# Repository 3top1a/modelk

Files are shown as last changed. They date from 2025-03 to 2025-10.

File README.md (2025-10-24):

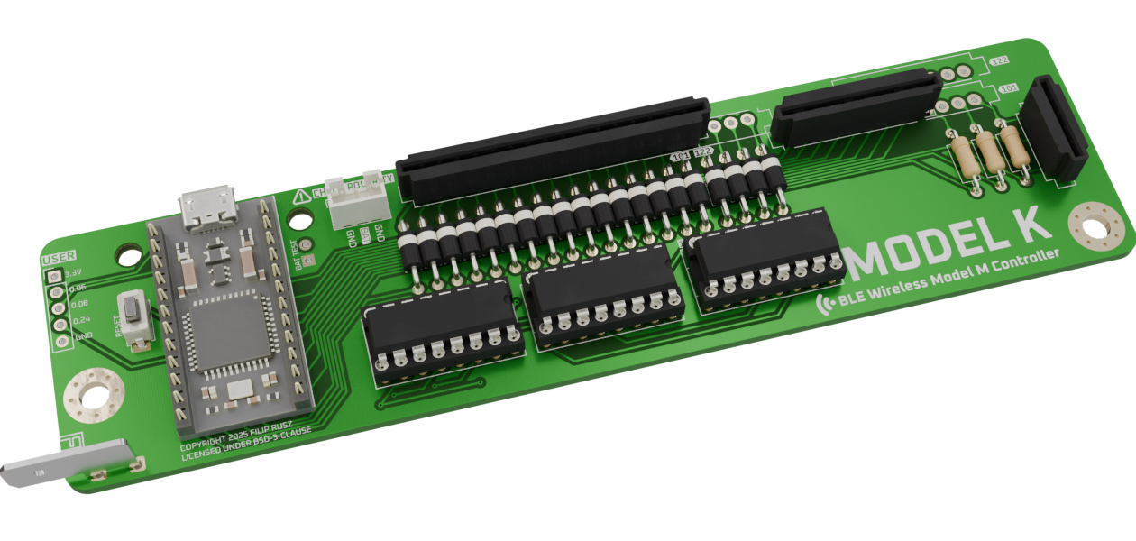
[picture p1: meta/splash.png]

<sup><sub>Render may be of an outdated version, the images below are from a CI/CD render and are always up-to-date. Only compatible with nice!nano, other MCUs won't work</sub></sup>
<div style="display: inline-flex; flex-direction: row; align-content: space-around; justify-content: space-evenly;">
  
  
</div>

Modelk is a custom replacement controller designed to add wireless Bluetooth Low Energy functionality to classic IBM Model M keyboards. This drop-in controller lets you convert your vintage buckling spring keyboard to wireless without permanent modification, preserving the original controller.

## Features

<!-- TODO Supported keyboards, M122 not tested yet -->
- Fully wireless with BLE (Bluetooth Low Energy)
- Battery powered with 3+ weeks of battery life[^batery]
- USB C for drag-and-drop programming, charging and wired use
- Compatible with IBM Model M 101/102 layouts (122-key compatibility uncertain as I do not own one yet)[^models]
- [Open source ZMK firmware](https://github.com/3top1a/modelk-zmk), with [CI/CD builds](https://github.com/3top1a/modelk-zmk/actions/workflows/build.yml)
- Works as a shield for the [nice!nano](https://nicekeyboards.com/nice-nano), built on top of the Nordic nRF52840
- All components are THT and easy to solder/repair/replace
- Three high-frequency user-configurable pins for your solenoid/speaker desires

## Hardware

### PCB

The PCB is designed in KiCad 9. This repository has a CI/CD pipeline that automatically renders the schematic into a [PDF](https://github.com/3top1a/modelk/blob/pcb-artifacts/pcb/autogen/modelk-schematic.pdf)/[SVG](https://github.com/3top1a/modelk/blob/pcb-artifacts/pcb/autogen/modelk-schematic.svg) and generates gerbers for [JLCPCB](https://github.com/3top1a/modelk/blob/pcb-artifacts/pcb/autogen/jlcpcb.zip) and [PCBWAY](https://github.com/3top1a/modelk/blob/pcb-artifacts/pcb/autogen/pcbway.zip).



### Components

See the automatically generated [iBOM](https://github.com/3top1a/modelk/blob/pcb-artifacts/pcb/autogen/ibom.html) (you will need to download the .html file and open it in your browser for now).

For a full assembly, you will need:
- 1x Modelk PCB
- 2x 74HC595 shift register ICs, preferably with DIP-16 sockets (three for M122s)
- 3x 150R resistors for the LEDs (if you have any)
- 16x 1N4148 diodes (20 for M122s)
- 1x 6x3mm reset switch ([GME](https://www.gmelectronic.com/v/1500827/kls-ts3601-43-180-microswitch) for reference)
- 1x battery and its corresponding connector (on board is JST-PH 2mm and a 2.54mm pin header for power profiling)
- PCB Faston mount ([GME](https://www.gmelectronic.com/v/1500147/dj6116-63x08-faston-do-dps-63mm) for reference)
- Appropriate [Trio-mate](https://www.te.com/en/product-6-520415-6.html) or [Connfly](https://www.tme.eu/cz/details/ds1020-16st1d/konektory-ffc-fpc-raster-2-54mm/connfly/) connectors
- 1x nice!nano with Mill Max low profile sockets

Your keyboard might contain 16+12 or 16+8+4 connectors, make sure you order the ones you need! The board supports both of them.

### Equipment

You will need:

- A Temperature-controlled soldering iron
- Some Electronics-grade solder
- Fume extraction or well-ventilated area
- A multimeter for troubleshooting
- Isopropyl alcohol for cleaning
- Kapton tape for securing the battery

### Assembly

Start with a blank PCB and solder the 16 pin connector.

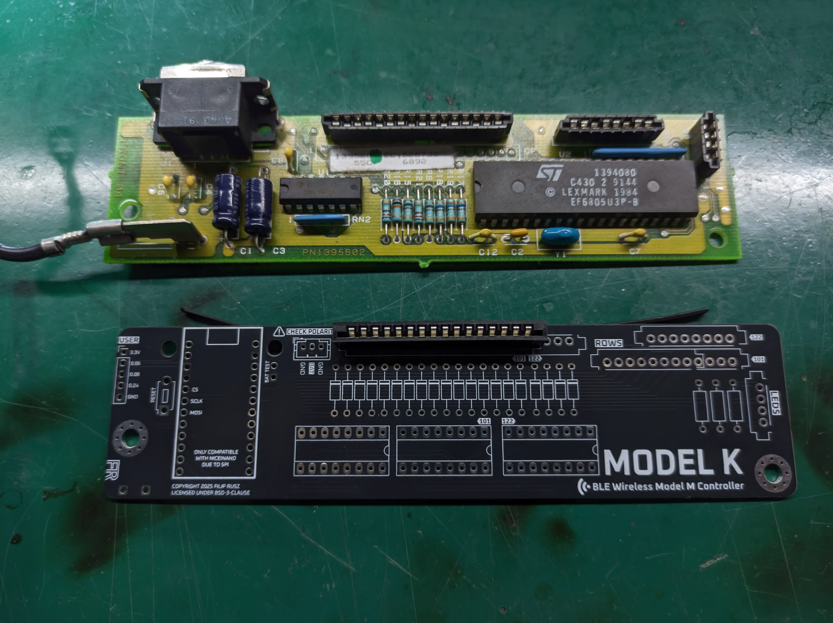
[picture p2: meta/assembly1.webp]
First picture of assembly, Modelk PCB on the bottom with one connector soldered and the original controller on top


On the bottom you can see the board I am assembling (revision [0.10](https://github.com/3top1a/modelk/tree/0.10)), and on the top you can see the original controller that came with my keyboard. Because I am using Connfly connectors and not the original TE Trio-mate, I need to rotate them 180° as they work differently.

> [!IMPORTANT]
> If you are using **Connfly** connectors, make sure to rotate them 180°! This sounds counter-intuitive, but **your board will not work otherwise**!

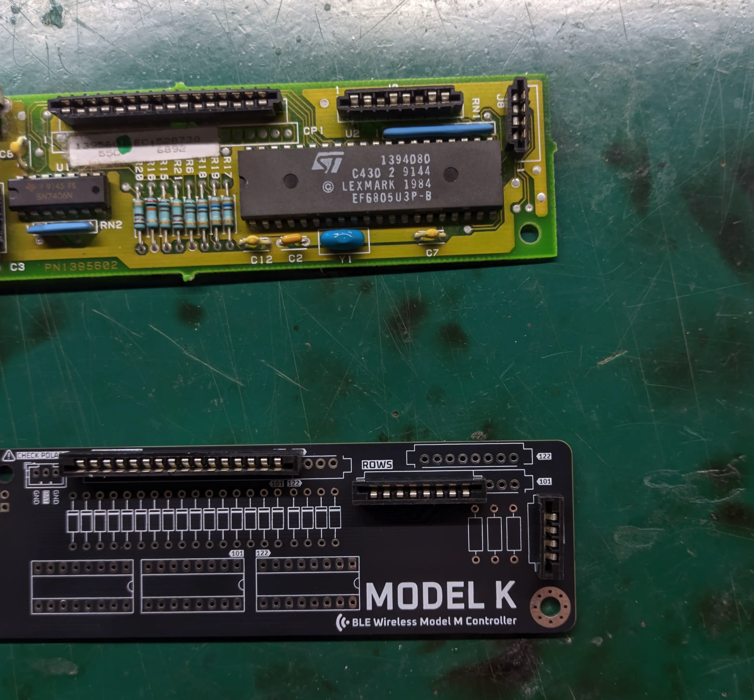
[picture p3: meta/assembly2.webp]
Second picture of assembly, Modelk PCB on the bottom with all connectors soldered and the original controller on top


As my keyboard comes with 16+8+4 connectors, I will solder the appropriate connectors, also rotated just like the 16 pin one.

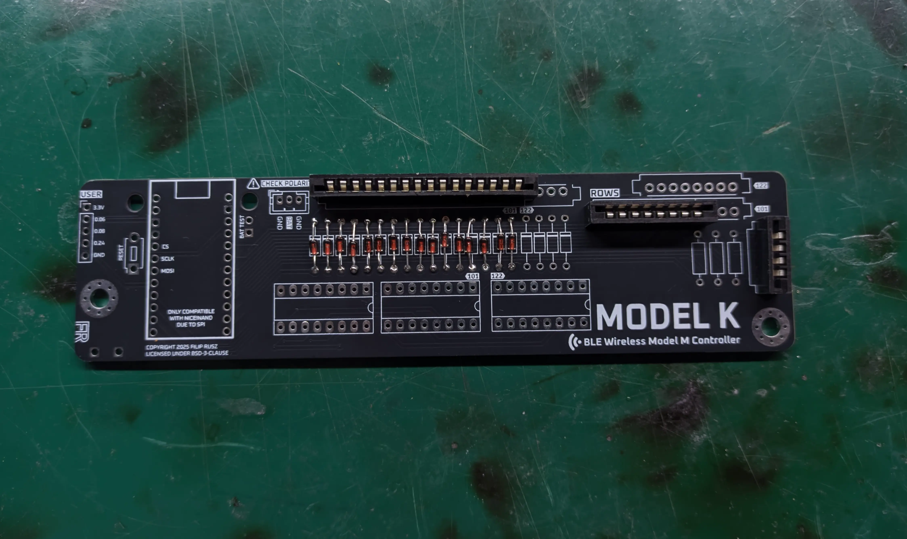
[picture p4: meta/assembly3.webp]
Third picture of assembly, with diodes soldered


Next up are the diodes, as I have a 101-key keyboard, I will only populate the 16 left-most diodes. Pay attention to the orientation of the diodes, the black strip has to be on top, as indicated on the silkscreen.

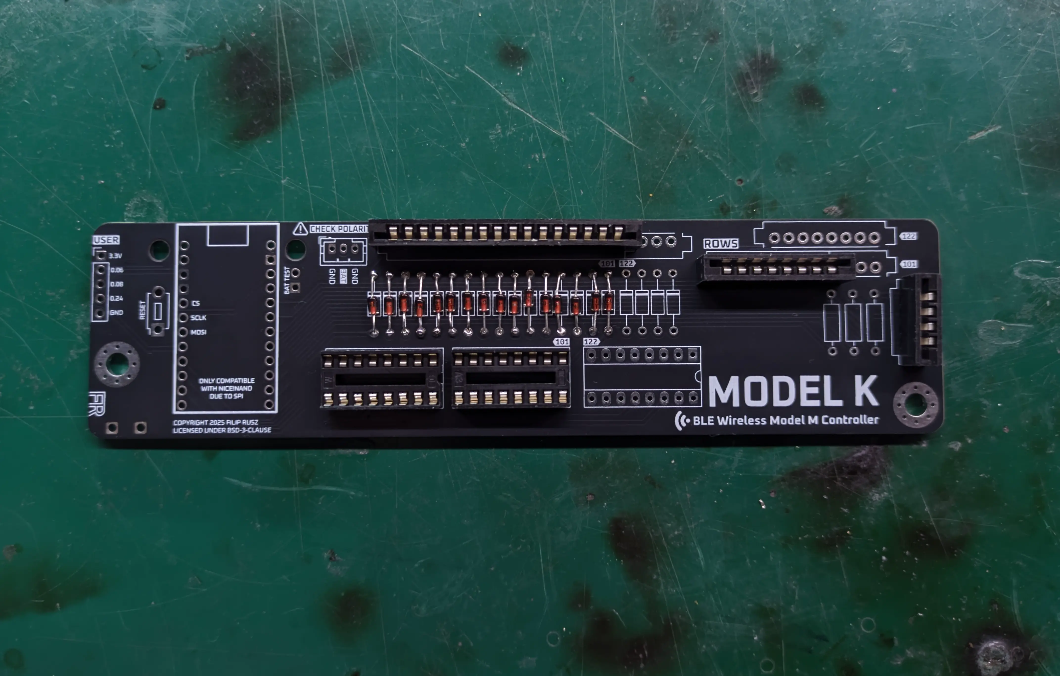
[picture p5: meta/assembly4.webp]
Fourth picture of assembly, with IC sockets soldered


Then the IC sockets, orientation again indicated on the silkscreen (don't forget to populate them!)

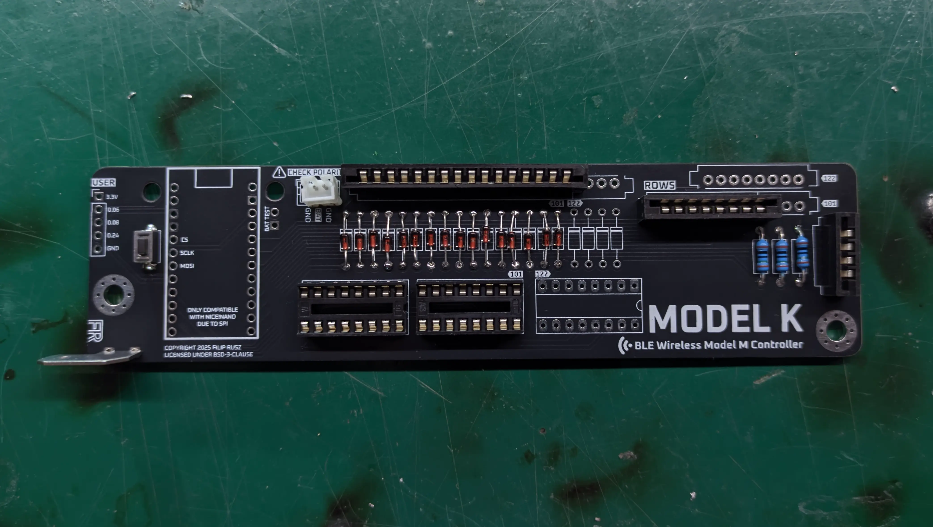
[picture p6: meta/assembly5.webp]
Fifth picture of assembly, with resistors, the reset switch, grounding Faston mount and battery connector soldered


I will skip a bit here, and solder (from left to right) the Faston grounding mount, reset switch, battery connector and resistors. Just be careful soldering the Faston mount, it will get hot.

> [!CAUTION]
> Quadruple check the orientation of the battery connector! The nice!nano doesn't have reverse polarity protection and you will destroy it otherwise.

All that is left is to solder the low profile sockets, solder pins to the nice!nano (see  [official guide](https://nicekeyboards.com/docs/nice-nano/getting-started#socketing-the-nicenano)), and populate the ICs.

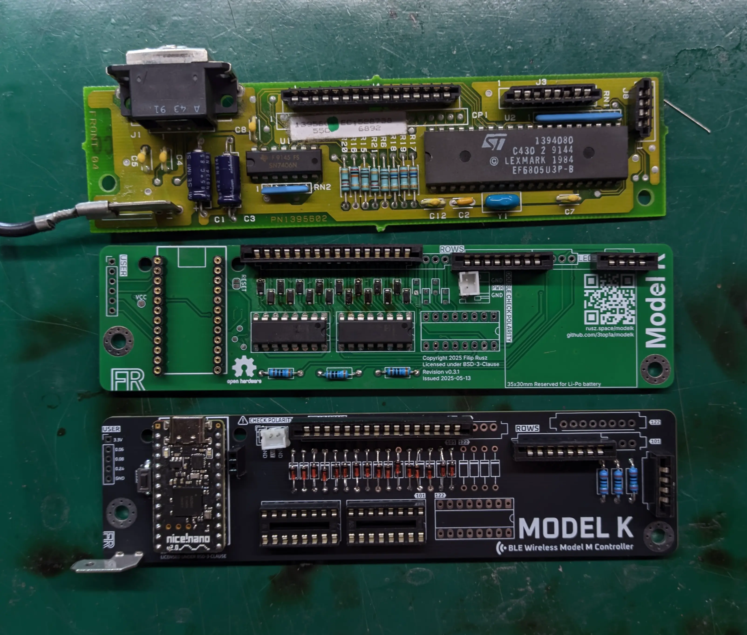
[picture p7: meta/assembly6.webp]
Final picture with finished board on the bottom, a previous iteration in the middle and original controller on top


Here you can see the finished board (without ICs, I forgot and spent 10 minutes debugging SPI because of it), a previous iteration (revision 0.3.1) and the original controller.

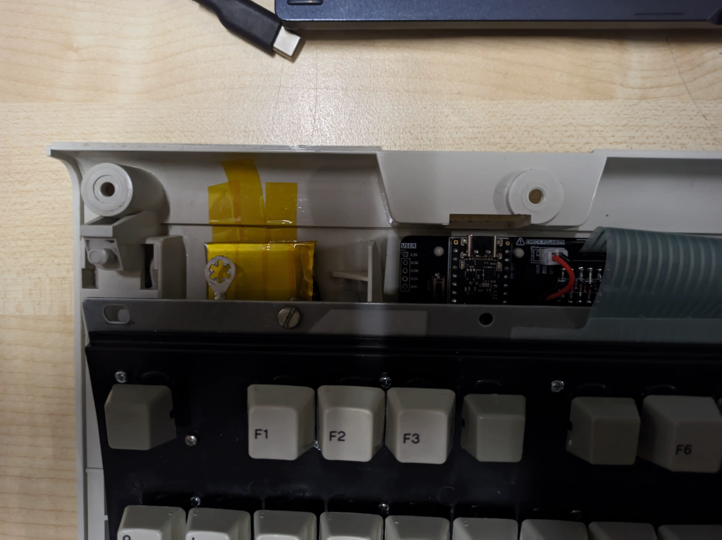
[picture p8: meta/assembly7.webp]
Modelk controller inside a Model M keyboard


Now you just need to put it into the keyboard, secure the battery with kapton tape, and mount the original grounding wire.

## Software

For now, see the [modelk-zmk](https://github.com/3top1a/modelk-zmk) repository for the ZMK firmware. Might get merged into this repository.

Installation:

- Download firmware from the modelk-zmk [CI/CD builds](https://github.com/3top1a/modelk-zmk/actions/workflows/build.yml) ([or click here for the latest firmware](https://nightly.link/3top1a/modelk-zmk/workflows/build/master/firmware.zip))
- Connect your nice!nano via USB
- Double-tap the reset button to enter bootloader mode (the little blue light should stay on)
- Your computer will detect a USB drive
- Drag and drop the firmware file (.uf2) onto this drive
- The nice!nano will disconect itself once the process is complete
- Enjoy a working wireless Model M!

By default, right alt switches to a function layer, where escape toggles USB/BT and F1-F3 toggles BT profiles, F4 clears the current BT profile, F6-F8 controls multimedia, Print Screen unlocks ZMK Studio and **Pause reboots into bootloader for updating firmware**.
You can, of course, completely redesign the layout.

## Credits

Huge kudos go to [John Hawthorn](https://www.johnhawthorn.com/) for his [Model H](https://modelh.club/) controller that inspired this project. This repo started as a fork, but now doesn't share any files.

[^batery]: currently ~3 weeks on a 400mAh battery with revision 0.3.1, will be better on newer boards

[^models]: Tested on: 1386716

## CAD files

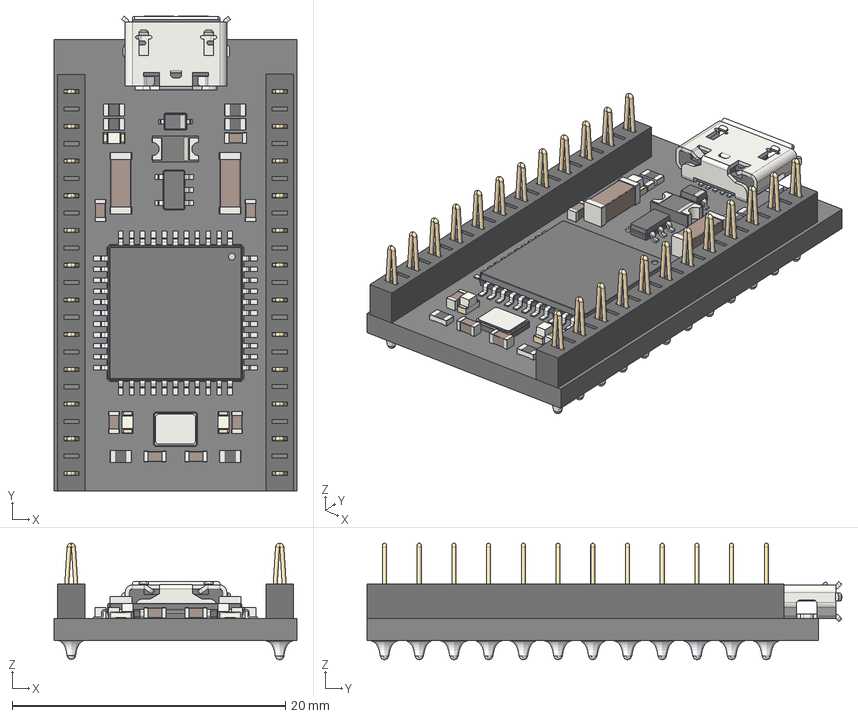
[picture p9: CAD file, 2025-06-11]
pcb/3d/ProMicro.step
17.8 x 34.7 x 8.54 mm
TQFP-44_10x10mm_P0.8mm
USB_Micro-B_Molex_47346-0001
R_0603 x 6
LED_0603_1608Metric x 3
C_0603_1608Metric x 8
Crystal_SMD_3225-4Pin_3.2x2.5mm
D_SOD-323
D_1206_3216Metric
TSOT-23-5
C_1806_4516Metric x 2
conthrough x 2

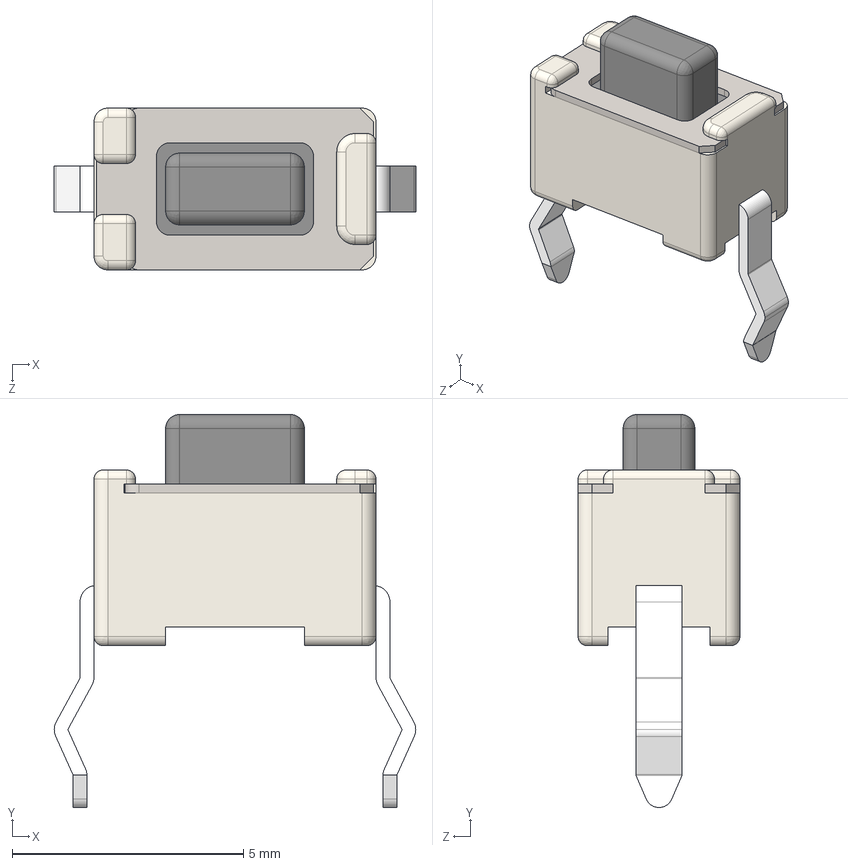
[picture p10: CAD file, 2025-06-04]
pcb/3d/SKHLABA010.stp
7.82 x 8.50 x 3.50 mm

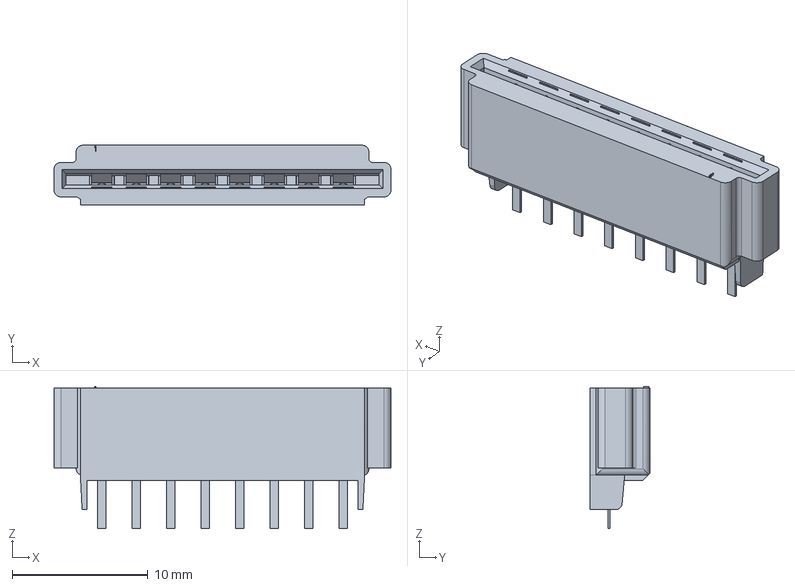
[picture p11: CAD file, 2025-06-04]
pcb/3d/5-520315-8.stp
24.8 x 4.39 x 10.5 mm

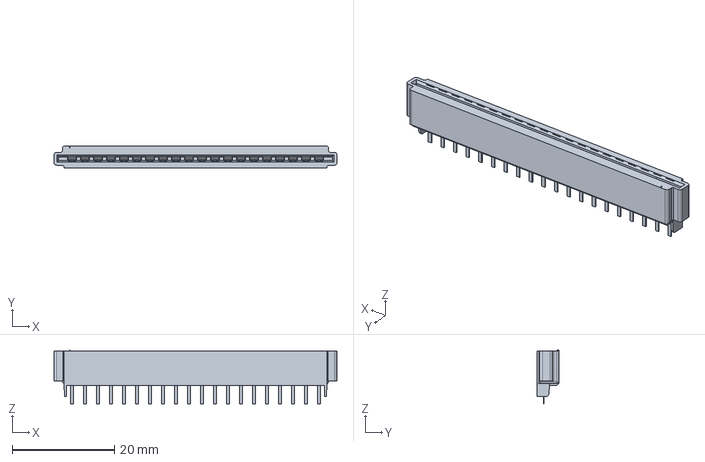
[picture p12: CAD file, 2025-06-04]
pcb/3d/7-520315-0.stp
55.3 x 4.39 x 10.5 mm

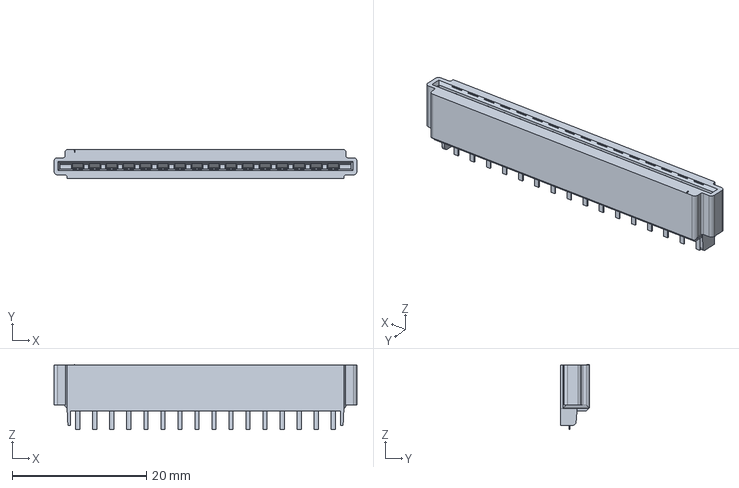
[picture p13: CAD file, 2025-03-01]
pcb/3d/6-520415-6.stp
45.2 x 4.39 x 9.73 mm

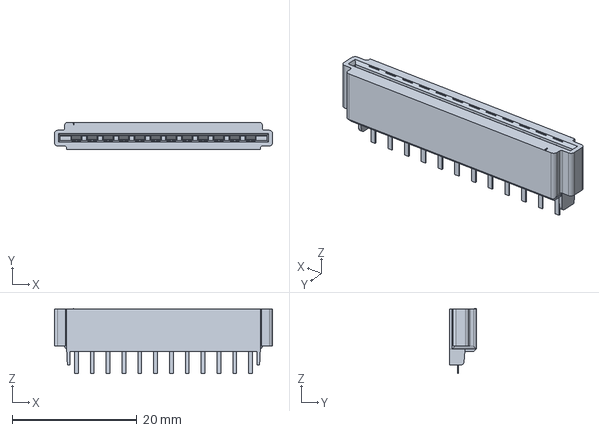
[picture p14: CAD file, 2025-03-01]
pcb/3d/6-520315-2.stp
35.0 x 4.39 x 10.5 mm

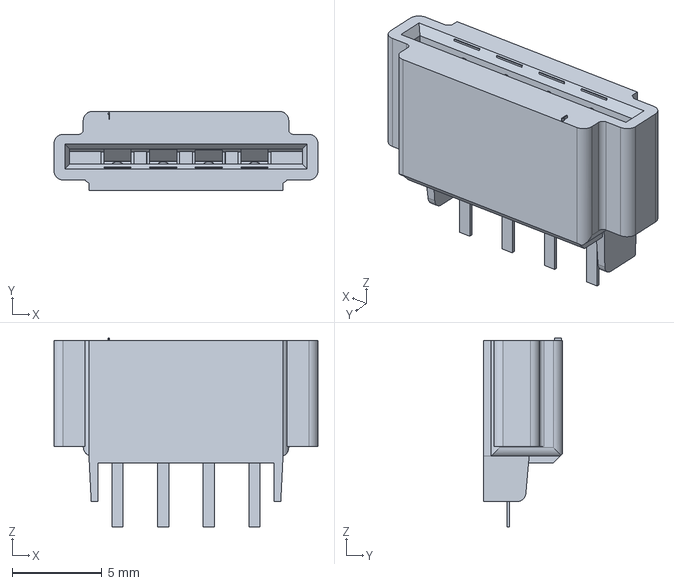
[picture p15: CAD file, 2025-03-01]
pcb/3d/5-520315-4.stp
14.7 x 4.39 x 10.5 mm

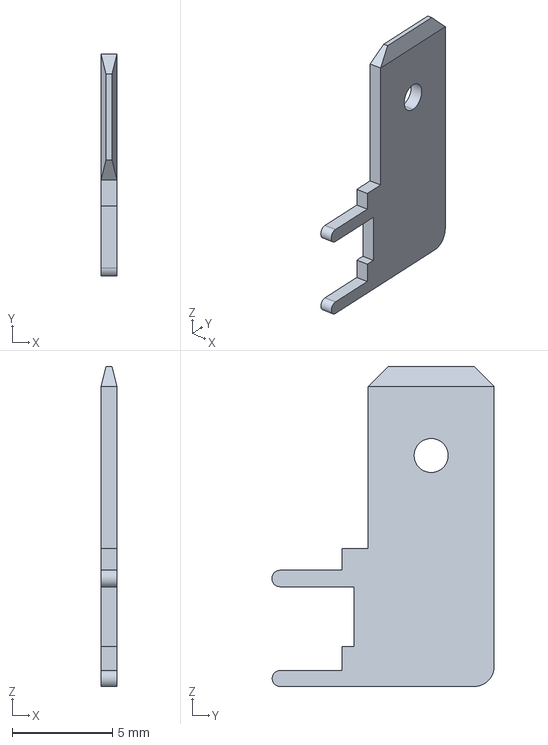
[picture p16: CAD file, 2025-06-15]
pcb/3d/928814-1.stp
0.8 x 11.1 x 16.0 mm

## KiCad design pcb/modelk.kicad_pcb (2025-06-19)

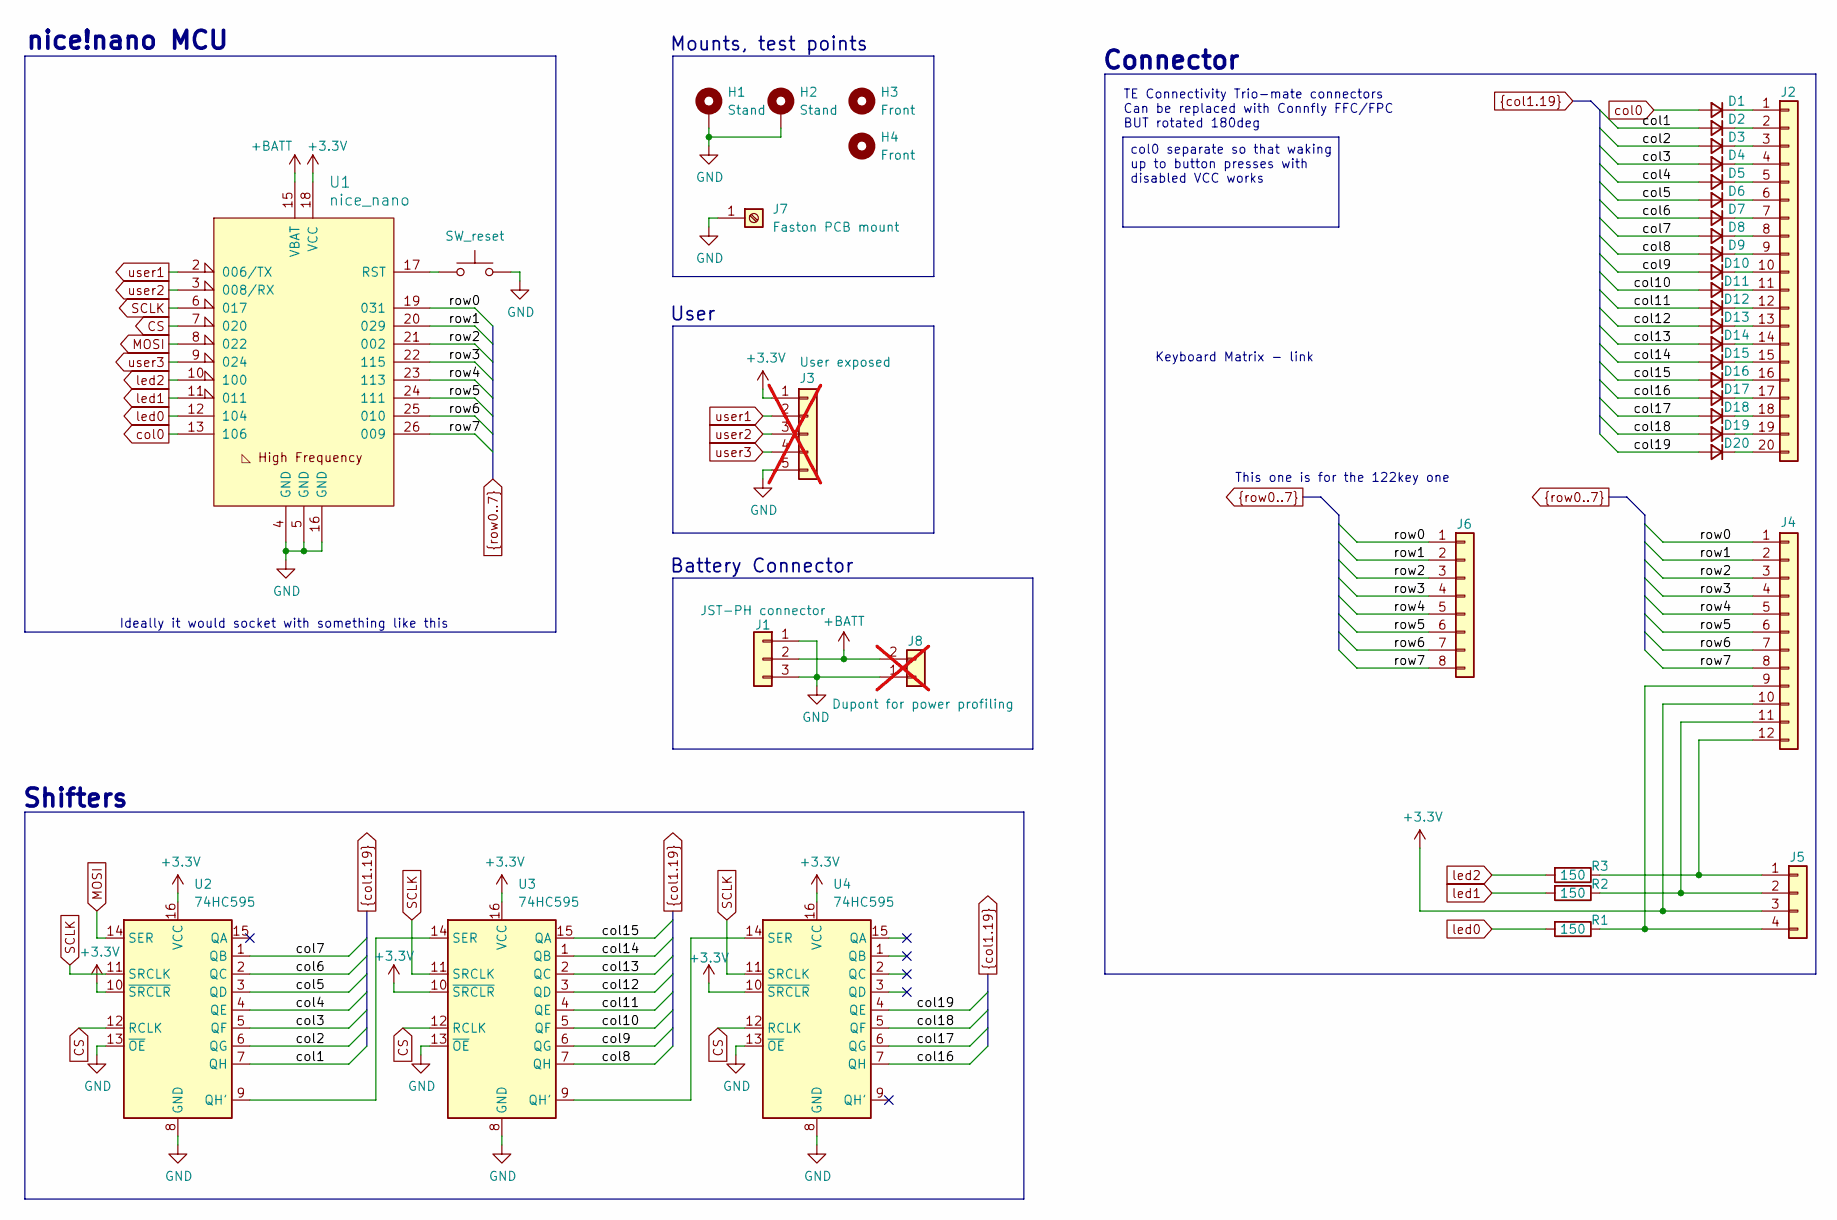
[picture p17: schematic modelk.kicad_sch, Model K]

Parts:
D1, D2, D3, D4, D5, D6, D7, D8, D9, D10, D11, D12, D13, D14, D15, D16, D17, D18, D19, D20: D_Small; DO-35 smaller
H1, H2: Stand; MountingHole_4mm_Pad_Via
H3, H4: Front; Hole 3.5mm
J1: JST-PH connector; JST_PH_B3B-PH-K_1x03_P2.00mm_Vertical
J2: Conn_01x20; ffc-cols20
J3: User exposed; PinHeader_1x05_P2.54mm_Vertical; not fitted
J4: Conn_01x12; ffc-rows12
J5: Conn_01x04; ffc-leds4
J6: Conn_01x08; ffc-rows8
J7: Faston PCB mount; faston-mount
J8: Dupont for power profiling; BatteryHeader; not fitted
R1, R2, R3: 150; R_Axial_DIN0207_L6.3mm_D2.5mm_P10.16mm_Horizontal
SW1: SW_reset; SW_PUSH_1P1T_6x3.5mm_H4.3_APEM_MJTP1243
U1: nice_nano
U2, U3, U4: 74HC595; DIP-16-74HC595

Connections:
+3.3V: J3.1, J4.10, J5.3, U1.18 (VCC), U2.10 (~SRCLR), U2.16 (VCC), U3.10 (~SRCLR), U3.16 (VCC), U4.10 (~SRCLR), U4.16 (VCC)
+BATT: J1.2, J8.2, U1.15 (VBAT)
/col1: D2.2 (A), U2.7 (QH)
/col2: D3.2 (A), U2.6 (QG)
/col3: D4.2 (A), U2.5 (QF)
/col4: D5.2 (A), U2.4 (QE)
/col5: D6.2 (A), U2.3 (QD)
/col6: D7.2 (A), U2.2 (QC)
/col7: D8.2 (A), U2.1 (QB)
/col8: D9.2 (A), U3.7 (QH)
/col9: D10.2 (A), U3.6 (QG)
/col10: D11.2 (A), U3.5 (QF)
/col11: D12.2 (A), U3.4 (QE)
/col12: D13.2 (A), U3.3 (QD)
/col13: D14.2 (A), U3.2 (QC)
/col14: D15.2 (A), U3.1 (QB)
/col15: D16.2 (A), U3.15 (QA)
/col16: D17.2 (A), U4.7 (QH)
/col17: D18.2 (A), U4.6 (QG)
/col18: D19.2 (A), U4.5 (QF)
/col19: D20.2 (A), U4.4 (QE)
/row0: J4.1, J6.1, U1.19 (031)
/row1: J4.2, J6.2, U1.20 (029)
/row2: J4.3, J6.3, U1.21 (002)
/row3: J4.4, J6.4, U1.22 (115)
/row4: J4.5, J6.5, U1.23 (113)
/row5: J4.6, J6.6, U1.24 (111)
/row6: J4.7, J6.7, U1.25 (010)
/row7: J4.8, J6.8, U1.26 (009)
CS: U1.7 (020), U2.12 (RCLK), U3.12 (RCLK), U4.12 (RCLK)
GND: H1.1, H2.1, J1.1, J1.3, J3.5, J7.1, J8.1, SW1.1, U1.4 (GND), U1.5 (GND), U1.16 (GND), U2.8 (GND), U2.13 (~OE), U3.8 (GND), U3.13 (~OE), U4.8 (GND), U4.13 (~OE)
MOSI: U1.8 (022), U2.14 (SER)
unnamed: D1.1 (K), J2.1
unnamed: D2.1 (K), J2.2
unnamed: D3.1 (K), J2.3
unnamed: D4.1 (K), J2.4
unnamed: D5.1 (K), J2.5
unnamed: D6.1 (K), J2.6
unnamed: D7.1 (K), J2.7
unnamed: D8.1 (K), J2.8
unnamed: D9.1 (K), J2.9
unnamed: D10.1 (K), J2.10
unnamed: D11.1 (K), J2.11
unnamed: D12.1 (K), J2.12
unnamed: D13.1 (K), J2.13
unnamed: D14.1 (K), J2.14
unnamed: D15.1 (K), J2.15
unnamed: D16.1 (K), J2.16
unnamed: D17.1 (K), J2.17
unnamed: D18.1 (K), J2.18
unnamed: D19.1 (K), J2.19
unnamed: D20.1 (K), J2.20
unnamed: J4.9, J5.4, R1.1
unnamed: J4.11, J5.2, R2.1
unnamed: J4.12, J5.1, R3.1
unnamed: SW1.2, U1.17 (RST)
unnamed: U2.9 (QH'), U3.14 (SER)
unnamed: U3.9 (QH'), U4.14 (SER)
SCLK: U1.6 (017), U2.11 (SRCLK), U3.11 (SRCLK), U4.11 (SRCLK)
col0: D1.2 (A), U1.13 (106)
led0: R1.2, U1.12 (104)
led1: R2.2, U1.11
led2: R3.2, U1.10 (100)
user1: J3.2, U1.2 (006/TX)
user2: J3.3, U1.3 (008/RX)
user3: J3.4, U1.9 (024)

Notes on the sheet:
Ideally it would socket with something like this
Shifters
User
Keyboard Matrix - link
Mounts, test points
TE Connectivity Trio-mate connectors Can be replaced with Connfly FFC/FPC BUT rotated 180deg
Connector
Battery Connector
nice!nano MCU
This one is for the 122key one
col0 separate so that waking up to button presses with disabled VCC works

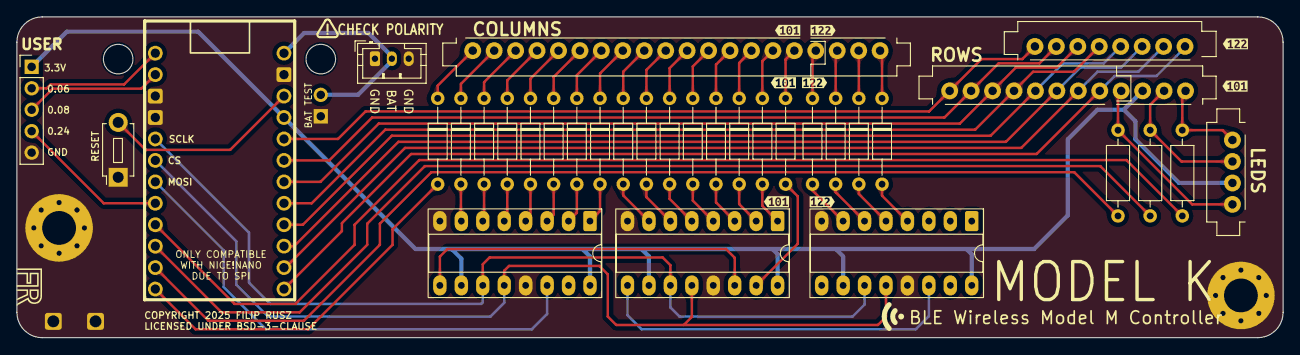
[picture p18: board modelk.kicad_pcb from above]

Board: 2 copper layers, 150.0 x 38.0 mm, 48 parts (0 on the bottom side), 66 nets.

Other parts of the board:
kibuzzard-684FF5A3: G***; kibuzzard-684FF5A3
kibuzzard-684FF45F, kibuzzard-684FF45F#2, kibuzzard-684FF45F#3, kibuzzard-684FF45F#4: G***; kibuzzard-684FF45F
kibuzzard-684FF466, kibuzzard-684FF466#2, kibuzzard-684FF466#3: G***; kibuzzard-684FF466

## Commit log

2025-04-30 version 0.2
    [modelh.kicad_pcb, modelh.kicad_sch]
2025-04-30 Added license
    [modelh.kicad_pcb]
2025-05-12 Rev 0.3
    [modelh.kicad_pcb, modelh.kicad_sch]
2025-05-12 Small edits
    [modelh.kicad_pcb]
2025-05-12 Make it compatable with old pro micro
    [modelh.kicad_pcb, modelh.kicad_sch]
2025-05-13 v3.1; made it uncompatible because HF pins
    [modelh.kicad_pcb, modelh.kicad_sch]
2025-05-20 Added actual reset switch
    [modelh.kicad_pcb, modelh.kicad_sch]
2025-06-04 Aligned connectors correctly, added second 4 pin footprint
    [5-520315-8.stp, 7-520315-0.stp, SKHLABA010.stp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]
2025-06-04 Added testpad labels, ibom
    [modelh.kicad_pcb, modelh.kicad_sch]
2025-06-04 Added third hole for M122
    [modelh.kicad_pcb, modelh.kicad_sch]
2025-06-04 101 key was correct
    [modelh.kicad_pcb, modelh.kicad_sch]
2025-06-04 Mostly stylistic changes
    [modelh.kicad_pcb, modelh.kicad_sch]
2025-06-11 Better models, added SGA font, col0 separate
    [ProMicro.step, modelh.kicad_pcb, modelh.kicad_sch]
2025-06-14 v0.7, too much to comment
    [modelh.kicad_pcb, modelh.kicad_sch]
2025-06-14 Rename files
    [modelk.kicad_pcb, modelk.kicad_sch, modelk.sch]
2025-06-14 Shim is now outdated
    [shim.scad, shim.stl]
2025-06-15 Added faston ground connector
    [928814-1.stp, modelk.kicad_pcb, modelk.kicad_sch]
2025-06-15 Fixed DRC
    [modelk.kicad_pcb, modelk.kicad_sch]
2025-06-15 Move traces so ground pour is continuous
    [modelk.kicad_pcb]
2025-06-15 Move stuff
    [modelk.kicad_pcb]
2025-06-15 Added battery header for profiling
    [modelk.kicad_pcb, modelk.kicad_sch]
2025-06-15 Removed mount holes from ffc connectors
    This also fixes all DRC errors.
    [modelk.kicad_pcb, modelk.kicad_sch]
2025-06-15 Actions test
    [modelk.kicad_pcb, modelk.kicad_sch]
2025-06-15 All leds on high frequency pins
    [modelk.kicad_pcb, modelk.kicad_sch]
2025-06-17 Remade half the board
    Redid the visual language, standardized the font and its size.
    Moved diodes closer to connector.
    Text is all caps now.
    [modelk.kicad_pcb, modelk.kicad_sch]
2025-06-17 Better font
    [modelk.kicad_pcb]
2025-06-17 Embeded SGA font
    [modelk.kicad_pcb]
2025-06-17 Modified user text to be the actual pin
    [modelk.kicad_pcb]
2025-06-18 Added pictograms
    [modelk.kicad_pcb, modelk.kicad_sch]
2025-06-18 Fixed connector position
    Also added Designed In CZ text on silkscreen and distributed traces in
    the middle.
    [modelk.kicad_pcb, modelk.kicad_sch]
2025-06-18 Made silkscreen not intersect
    [modelk.kicad_pcb]
2025-06-19 Spaced out signal tracks, less vias
    [modelk.kicad_pcb, modelk.kicad_sch]
2025-06-19 One less via
    [modelk.kicad_pcb]
2025-06-19 Spaced out traces, zero vias!
    [modelk.kicad_pcb, modelk.kicad_sch]
2025-06-19 Fixed silkscreen
    [modelk.kicad_pcb]
2025-06-19 Updated sclk/cs silkscreen
    [modelk.kicad_pcb]

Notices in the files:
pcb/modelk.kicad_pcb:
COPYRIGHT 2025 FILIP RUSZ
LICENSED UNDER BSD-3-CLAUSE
